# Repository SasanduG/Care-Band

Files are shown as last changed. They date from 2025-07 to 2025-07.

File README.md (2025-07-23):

# 🧠 Wearable Safety Device for Dementia Patients

An affordable, IoT-based **smartwatch system** designed to improve the safety and well-being of **dementia patients** by providing **real-time location tracking**, **fall detection**, and **caregiver alerts** via GSM. Developed by Team InnovaTech at the University of Moratuwa.
<p align="center">
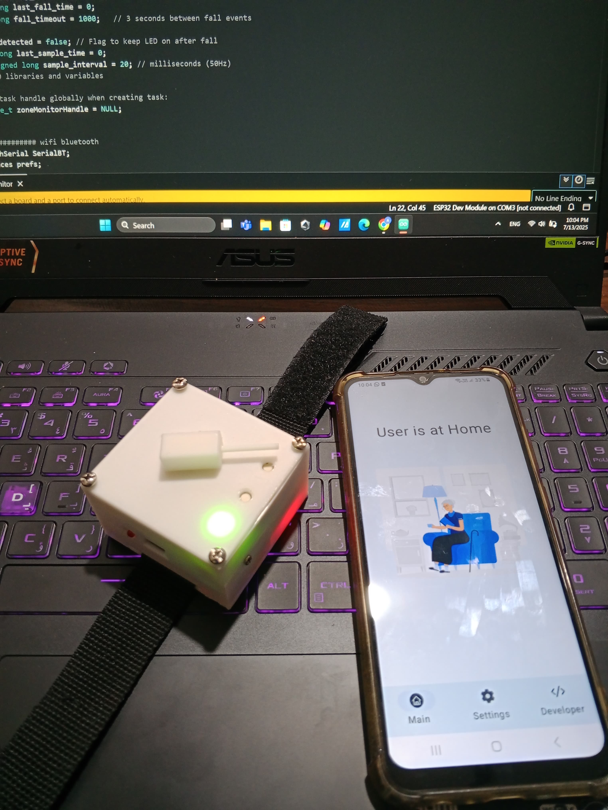
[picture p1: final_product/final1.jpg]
My Photo 1
  
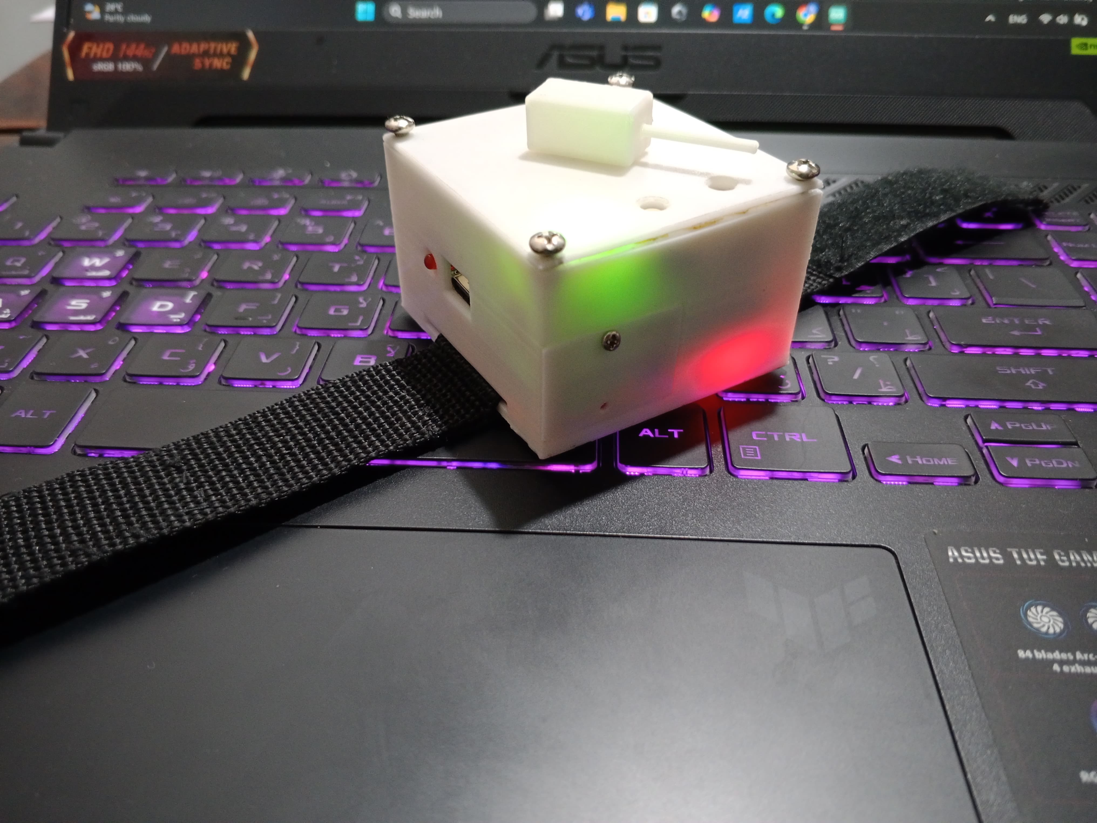
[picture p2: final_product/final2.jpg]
My Photo 2
  
</p>

---

## 📌 Overview

Dementia patients, especially in advanced stages, are prone to **wandering** and **accidental falls**, putting their safety at risk. This project proposes a cost-effective, comfortable, and practical **wearable solution** tailored for use in **Sri Lanka** and similar contexts. The device enables families and caregivers to monitor loved ones remotely using a mobile app and receive immediate alerts when a fall or unsafe movement is detected.

---

## 🎯 Key Features

- 📍 **GPS-Based Real-Time Tracking**
- ⚠️ **Fall Detection** using MPU6050 and ESP32
- 📡 **GSM Communication** via SIM800L (SMS & mobile data)
- 📲 **Android Mobile App** for caregivers with:
  - Live map tracking
  - Geo-fencing
  - Instant fall alerts
- 💡 **Status Indicators** for charging, connectivity, and alerts
- 🔋 **Rechargeable Battery** with safe charging module (TP4056)
- 🧰 **Custom Enclosure** and compact **PCB design**

---

## 🧩 Hardware Specifications

| Component | Description |
|---|---|
| **Microcontroller** | ESP32 WROOM-32 |
| **GPS Module** | NEO-6M |
| **GSM Module** | SIM800L |
| **Motion Sensor** | MPU6050 (3-axis Accelerometer + Gyroscope) |
| **Battery** | 3.7V 800mAh LiPo |
| **Charging Module** | TP4056 |
| **Enclosure** | 3D Printed (Custom Design) |

---

## 📱 Mobile Application (Android)

The custom-built mobile app (developed in **Kotlin**) provides:

- Real-time location display via **Google Maps API**
- Instant **fall and geofence** alerts
- Adjustable safe zone settings
- Simple and intuitive UI for caregivers

---

## 🛠 System Architecture

The system integrates:

- **ESP32** as the central controller
- **MPU6050** for fall detection
- **GPS** for live location updates
- **SIM800L** for GSM-based communication
- **Mobile app** for monitoring and control

All components are combined into a **compact PCB** and enclosed in a **watch-style casing** designed for elderly users.

---

## 🌍 Impact and Relevance

- Developed to meet the needs of families in **Sri Lanka**, where professional dementia care is limited.
- Uses **locally available** low-cost components.
- Final device cost is ~**8000 LKR**, aiming for **<10,000 LKR retail price** after optimization.
- Addresses growing elderly population and healthcare gaps.

---

## 👨‍🔬 Team Members

**Team InnovaTech – EN1190, University of Moratuwa**

- Wedamestrige A.N. (PCB & Circuit Design)
- Ranathunga R.J.K.O.H. (Mobile App Development)
- Garusinghe S.B. (Enclosure Design)
- Prabharsha H.W.D. (Enclosure Design)

---

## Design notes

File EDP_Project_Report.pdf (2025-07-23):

# Wearable Device for Dementia

# Patients

## EN 1190: Engineering Design Project


## University of Moratuwa

## Faculty of Engineering

Department of Electronics and Telecommunication Engineering

### Team InnovaTech

Name | Index

Ranathunga R.J.K.O.H. 230525U

Wedamestrige A.N. | 230687P
Prabharsha H.W.D. | 230495B
Garusinghe S.B. | 230197M

## Contents

1 Problem Description | 2
2 Product Feasibility | 4
3 Product Applications | 6
4 Product Specifications | 7
5 Product Architecture | 8
6 Enclosure | 11
7 PCB Design | 13
8 App Design | 15
9 Market Analysis | 17
10 Task Allocation | 18
11 Final Budget | 19

1

## 1 Problem Description

### Problem

Wandering is a common and worrying behavior among people living with dementia, especially in the moderate to advanced stages of the disease. Many patients leave their homes or care facilities without warning, often confused and unable to find their way back. This puts them at serious risk of accidents, injuries, getting lost, or even worse, if they are not found quickly.
In Sri Lanka, most families care for their loved ones at home, but with limited formal support services, providing round-the-clock supervision is a huge challenge. This constant responsibility causes significant stress and worry for caregivers. Sadly, traditional methods like manual watching or simple alarms often fail to prevent incidents. There is a real need for an affordable, practical, and easy-to-use solution that can help keep dementia patients safe and ease the daily burden on families who look after them.

### Justification for Problem Selection

Dementia is a significant and escalating global health crisis, profoundly impacting individuals and their families. This condition arises from damage to brain cells, disrupting their ability to communicate effectively. Such damage can stem from various causes, including diseases like Alzheimer’s, reduced cerebral blood flow (vascular dementia), atypical protein deposits (Lewy bodies), or other degenerative neurological conditions. Consequently, individuals with dementia frequently experience memory loss, disorientation, and a heightened propensity for wandering into unsafe environments, leading to potentially hazardous situations.
The global prevalence of dementia is staggering and on an upward trajectory. In 2020-2021, an estimated 55-57 million people were living with dementia worldwide, with approximately 10 million new diagnoses annually. Projections indicate a substantial increase in cases, reaching 82 million by 2030 and a remarkable 152 million by 2050. Dementia affects roughly 7% of individuals over 65, with prevalence rates escalating from about 3% in the 65-74 age group to nearly 50% in those 85 and older. The mortality rate associated with dementia has also seen a sharp rise, from 0.56 million deaths in 1990 to 1.62 million in 2019, with an anticipated 4.91 million deaths by 2050.
Sri Lanka mirrors this global demographic shift. By 2023, approximately 11.7% of its population was aged 65 or older, a notable increase from previous years, and this figure is projected to exceed 25% by 2041. In Sri Lanka’s rural and semi-urban areas, the prevalence of dementia among seniors is approximately 3.98%.
The worldwide aging of populations, including in Sri Lanka, directly correlates with an

2

escalating number of seniors and, consequently, a rise in dementia cases. This demographic trend underscores the urgent need to address the challenges posed by dementia.

### Proposed Solution

To address the growing challenges faced by dementia patients and their caregivers, we propose an affordable, wearable smartwatch system designed to improve safety and provide real-time monitoring. This solution combines modern IoT technology, low-cost hardware, and user-friendly design to help families manage dementia care more effectively, especially in Sri Lanka.
Our solution integrates a GPS module for real-time location tracking, a GSM module for communication with caregivers via mobile networks, and a motion sensor to detect abnormal movements such as falls. The smartwatch continuously monitors the patient’s location and sends alerts if they leave a predefined safe zone or if a fall is detected. This enables caregivers to respond quickly, improving patient safety and providing peace of mind. The device is designed to be lightweight, comfortable, and easy to use for elderly individuals, while also being cost-effective for families in Sri Lanka.

### Comparison with Existing Solutions

Although several tracking devices and smartwatches for dementia patients are already available globally, many of these products have significant limitations when applied in the context of Sri Lanka. Existing solutions tend to be:

- Expensive, making them inaccessible for many families in low- and middle-income

regions.

- Bulky or uncomfortable, reducing patient compliance for continuous wear.
- Limited local support and customization for the specific needs of Sri Lankan users,

such as language barriers or local network compatibility.

Our project aims to overcome these challenges by creating a cost-effective, easy-to-use smartwatch system tailored to local conditions. It uses affordable components, simple communication methods like SMS alerts, and a comfortable wearable design, making it suitable for everyday use by dementia patients and their caregivers in Sri Lanka.

3

## 2 Product Feasibility

### Technical Feasibility

The proposed solution is technically feasible because it uses widely available, cost-effective electronic components and well-established technologies. The ESP32 microcontroller, GPS, SIM800L, and MPU6050 are widely used and fully compatible with mobile app communication via internet or GSM.
- The ESP32 can connect to the internet via GSM or Wi-Fi to send patient location and

status data to a dedicated mobile app. This app provides caregivers with an intuitive interface for real-time monitoring, geo-fencing setup, and instant notifications.

- The mobile app can be developed using common frameworks such as Flutter or React

Native, which allow faster development and compatibility with Android devices.

- Instead of relying solely on SMS, the mobile app allows richer data (e.g., maps, reset

memory, restart, send message) and better user control while still using mobile networks for areas with limited Wi-Fi.

- The device is powered by a 3.7 V, 800 mAh, 25C LiPo battery, which provides a

lightweight, compact energy source suitable for continuous wearable use. The TP4056 module ensures safe recharging via USB.

- The MPU6050 sensor module combines a 3-axis accelerometer and a 3-axis gyroscope

to monitor the patient’s movements in real-time. It detects abnormal motion patterns such as sudden falls or impacts. The data is processed by the ESP32, and an alert is generated if an unusual event is detected.

The custom-designed PCB integrates all the essential modules on a compact board, ensuring stable electrical connections and efficient signal transmission while keeping the overall form factor small enough for a wearable enclosure. The smartwatch enclosure was designed using 3D modeling tools and fabricated through collaboration with Rysera Innovations and NMW Robotics, who provided high-quality 3D printing and prototyping services. This approach ensured that the enclosure met the required standards for fit, durability, and user comfort while keeping production local and cost-effective.

### Hardware Feasibility

The proposed smartwatch system is hardware-feasible because it uses affordable, widely available electronic components and proven fabrication methods that are within the capability of the team to assemble and test. Key aspects that prove hardware feasibility include:

4

- ESP32 microcontroller
- SIM800L GSM module
- MPU6050 accelerometer/gyroscope
- 3.7 V, 800 mAh, 25C LiPo battery
- TP4056 charging module
- GPS module

### Software Feasibility

The proposed system is also feasible from a software perspective because it relies on well-established development platforms, straightforward programming requirements, and technologies that are well supported by existing resources and tools.

- The ESP32 microcontroller will be programmed using the Arduino IDE which provide

extensive libraries and community support for modules like GPS, GSM (SIM800L), and MPU6050 sensors. This makes it easy to integrate location tracking, motion detection, and communication functions.

- The mobile app is being developed using Kotlin in Android Studio, which is the official

IDE for Android development. Using Kotlin ensures modern, clean, and efficient code that fully leverages Android’s capabilities. Native development provides better performance, easier access to phone features (like notifications, maps, and SMS handling), and smooth user experience for caregivers.

- Kotlin and Android Studio allow the team to build a clear, user-friendly interface

with map integration (e.g., Google Maps API), custom alerts, and easy controls for caregivers.

5

## 3 Product Applications

The proposed smartwatch-based tracking and safety system is primarily designed to assist dementia patients and their caregivers:

- Monitoring Dementia Patients
- Elderly Care
- Patient Monitoring in Hospitals

### Mobile application

The proposed system includes a custom-developed mobile application designed to work seamlessly with the smartwatch hardware. The mobile app acts as the user interface for caregivers, enabling them to monitor and manage the safety of dementia patients in real time. Our mobile application includes a lot of features like:

- Receives location and motion status data from the smartwatch via GSM/mobile net-

work.

- Displays the patient’s live location on an interactive map.
- Provides instant notifications if the patient leaves a predefined safe area (geo-fence) or

if a fall is detected.

- Allow caregivers to set or adjust safe zones easily.

6

## 4 Product Specifications

Parameter | Specification
Communication Method | GSM (SMS / Data for Mobile App Communica-
| tion)
Estimated Size | Compact, wrist-wearable form factor (custom
| PCB). 59mm x 55mm x 35.6mm enclosure box
Operating Time
Indicators | Charging LED: Shows charging status and
| charge completion
| Status LED: Indicates Wi-Fi connected, fall de-
| tected, or safe zone exited
Microcontroller | ESP32 Development Board
Location Module | GPS Module (NEO-6M)
Communication Module | SIM800L GSM Module
Motion Sensor | MPU6050 (3-axis Accelerometer + 3-axis Gyro-
| scope)
Battery | 3.7 V, 800 mAh, 25C LiPo Battery
Charging Circuit | TP4056 Li-Ion Charging Module

Table 1: Product Specifications

7

## 5 Product Architecture

The proposed smartwatch-based tracking and safety system is designed with a clear modular architecture that integrates hardware components, embedded software, and a native mobile application to deliver real-time monitoring and alert functionalities.
The hardware consists of several integrated modules mounted on a custom PCB:

### Hardware architecture

- ESP32 Microcontroller - Acts as the central processing unit, managing data from all

sensors and modules.

- GPS Module - Provides real-time location data to ESP32.
- SIM800L GSM Module - Handles mobile network communication, allowing the system

to send location and alert data to the mobile application via SMS or internet.

- MPU6050 Sensor - Continuously monitors the patient’s movements and detects falls

using accelerometer and gyroscope data.

- Power Supply - Powered by a 3.7 V, 800 mAh, 25C LiPo battery with a TP4056 charging

circuit.

- Indicators -

– Charging LED: Shows the battery’s charging status and charge completion.

– Status LED: Indicates Wi-Fi connectivity and provides visual alerts for fall detection or geo-fence breaches.

- Enclosure - All hardware is enclosed in a lightweight, ergonomic, 3D-printed smart-

watch casing for comfortable daily use.

### Software architecture

The system’s software architecture has two main parts:

1. Embedded Software:
- Runs on the ESP32 microcontroller.
- Continuously collects data from the GPS module and MPU6050 sensor.
- Detects safe zone breaches and falls using programmed logic.

8

- Communicate with the SIM800L module to send alerts and location data.
- Controls the status LED to provide immediate visual feedback.
2. Mobile Application:
- Developed natively in Kotlin using Android Studio.
- Receives data from the smartwatch via GSM/SMS or mobile data.
- Displays the patient’s live location on a map.
- Send notifications for safe zone exits and falls.
- Provides a simple interface for caregivers to view alerts and manage safe zone

settings.

### Block Diagram

Figure 1 shows the block diagram of our product.

1. ESP32
- The ESP32 is the central microcontroller. It collects data from the GPS, Ac-

celerometer, and (in your diagram) a Heart Rate Sensor. It processes this data to detect patient’s real-time location, patient’s motion status (e.g., fall detection), vital signs. It controls communication with the GSM module to send alerts.

2. GSM Module
- The GSM module connects the system to the mobile network. It sends SMS

messages or mobile data with the patient’s location and alert status (fall detected, left home, etc.). It may receive simple commands from the caregiver’s mobile app if needed.

3. GPS Module
- The GPS module receives signals from GPS satellites. It continuously provides

latitude and longitude data to the ESP32. This is used for real-time location tracking and geo-fencing.

4. Accelerometer
- The Accelerometer detects motion and orientation. It monitors sudden changes

in movement to detect falls. ESP32 uses this data to trigger alerts if abnormal motion is detected.

9

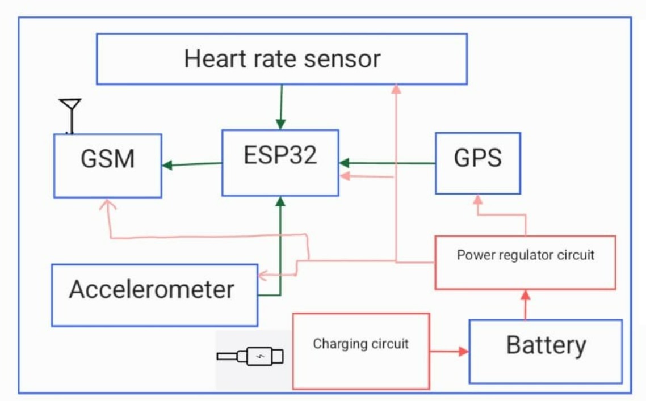
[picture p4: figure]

Figure 1: Block Diagram

5. Heart Rate Sensor
- This would monitor the patient’s pulse. The ESP32 can process this data for

additional health tracking.

6. Battery
- The Battery is a 3.7 V, 800 mAh LiPo cell. It provides portable power for the

entire system.

7. Charging Circuit
- This is the TP4056 charging module. It safely charges the battery via USB. It

also manages charging status (with the Charging LED).

8. Power Regulator Circuit
- Converts the battery’s raw 3.7 V to stable voltage levels required by the ESP32,

GPS, GSM, and sensors. Ensures each module gets the correct voltage and current to operate reliably.

10

## 6 Enclosure

### Initial Sketch

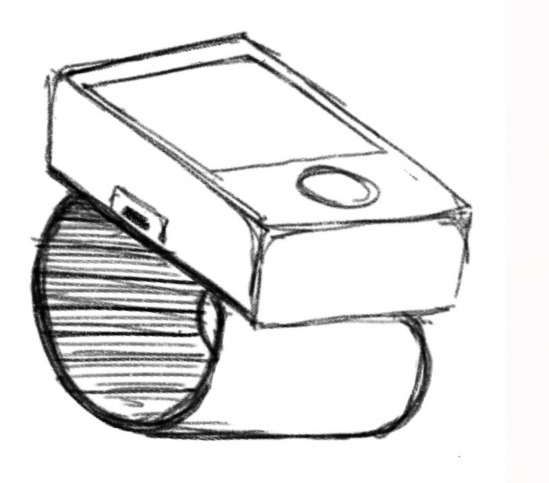
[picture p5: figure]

Figure 2: Initial sketch

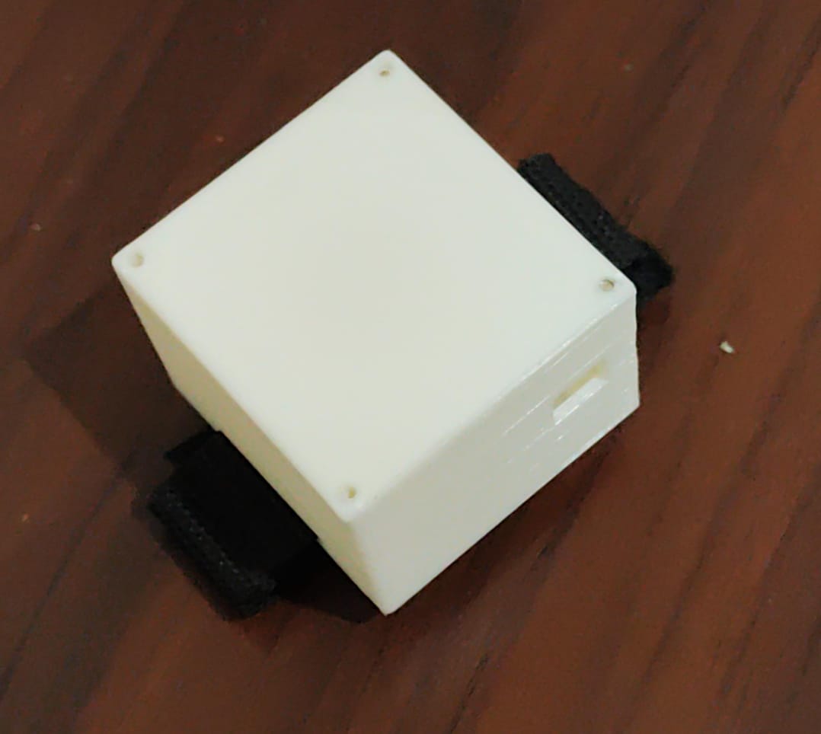
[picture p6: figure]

Figure 3: Final Product

11

### Final Enclosure

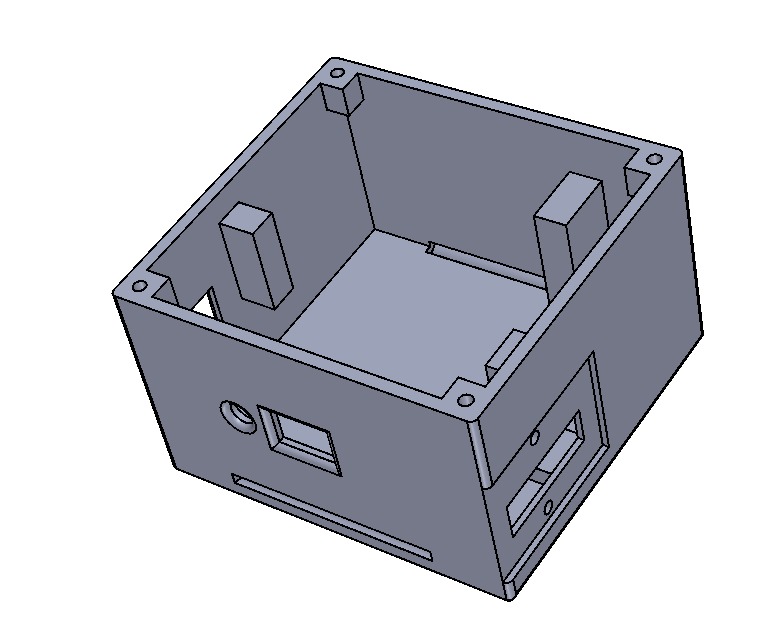
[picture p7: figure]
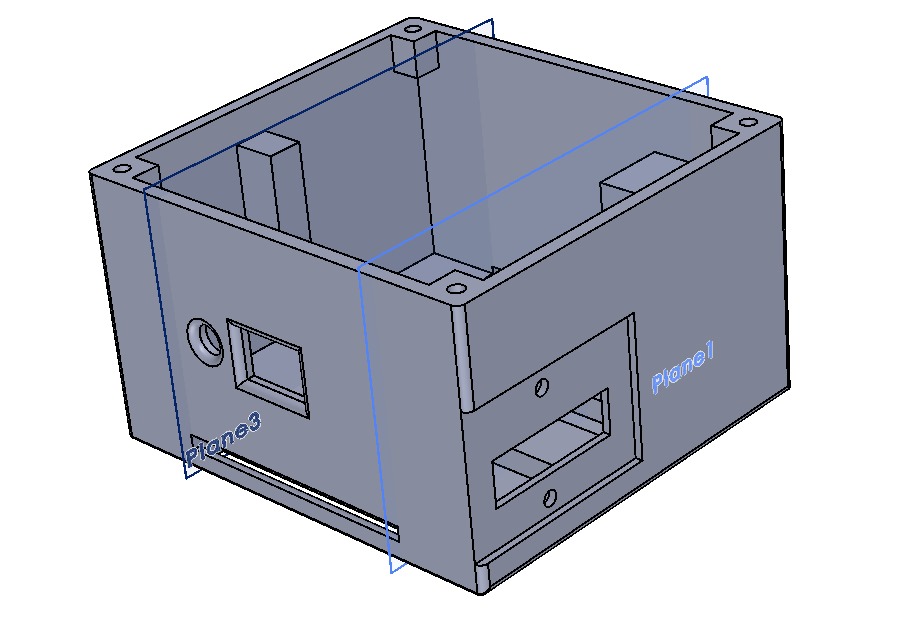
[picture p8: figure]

(a) Enclosure Design - View 1 | (b) Enclosure Design - View 2

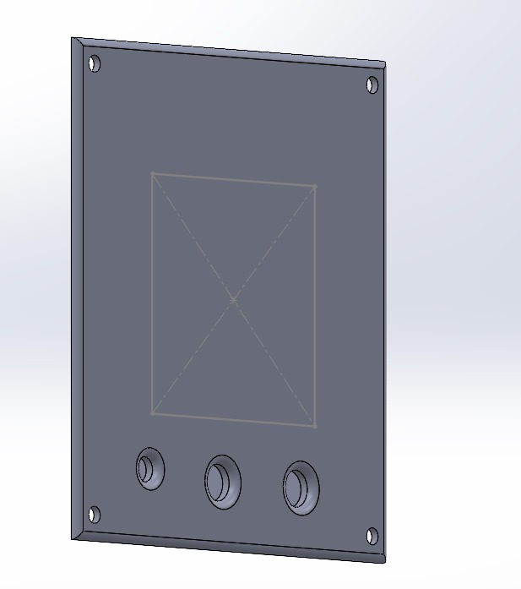
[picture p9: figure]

(c) SIM Lid | (d) Top Lid

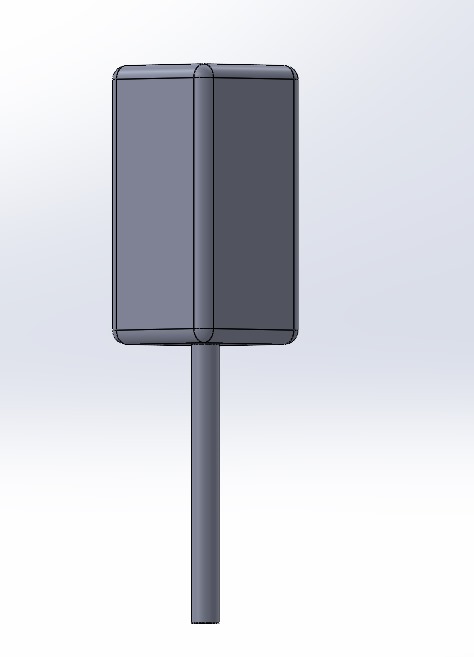
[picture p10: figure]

(e) Push Button
Mechanism
(f) Switch Part - View 1 | (g) Switch Part - View 2

Figure 4: 3D Model Components of the Smartwatch Enclosure and Assembly

12

## 7 PCB Design

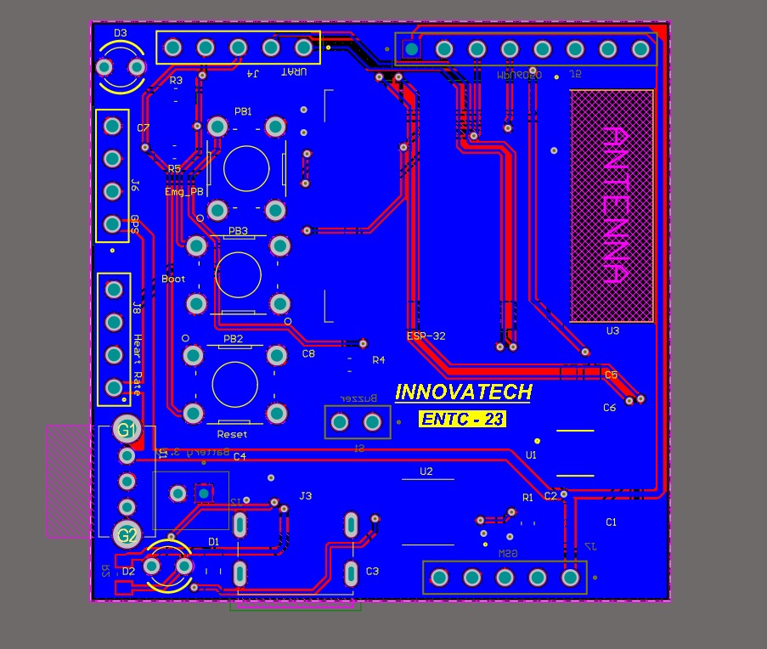
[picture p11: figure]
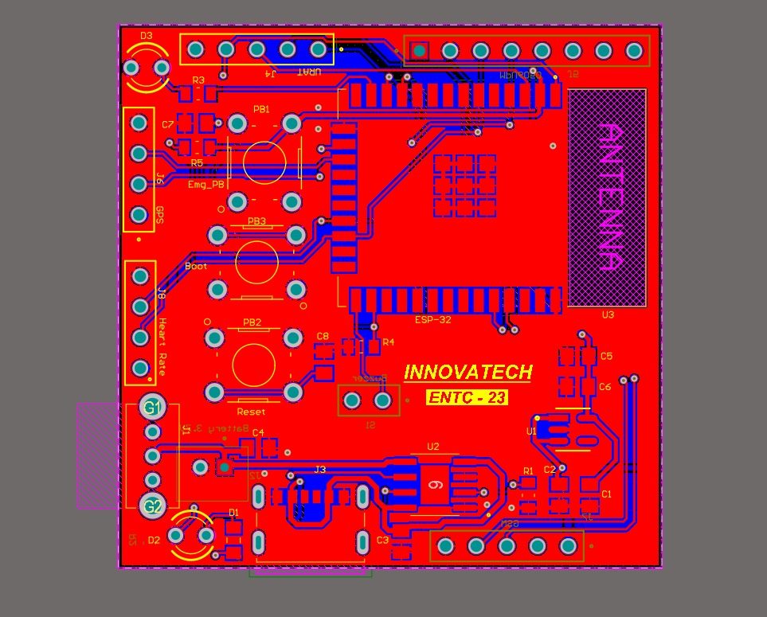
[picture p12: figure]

(a) Top layer | (b) Bottom layer

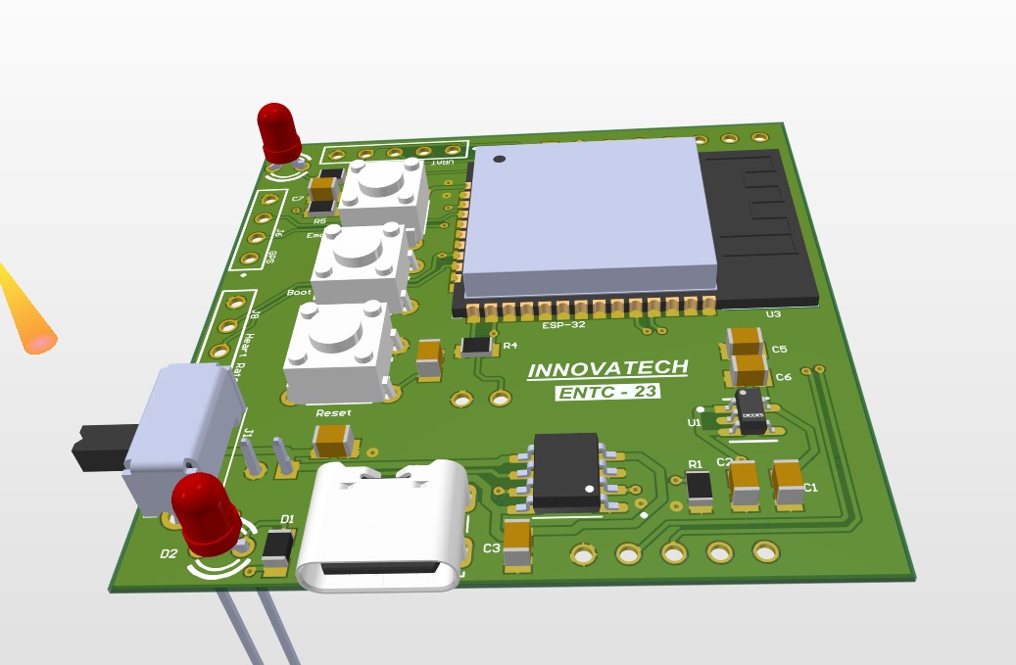
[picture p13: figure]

(c) 3D Model

Figure 5: PCB

13

### Schematic

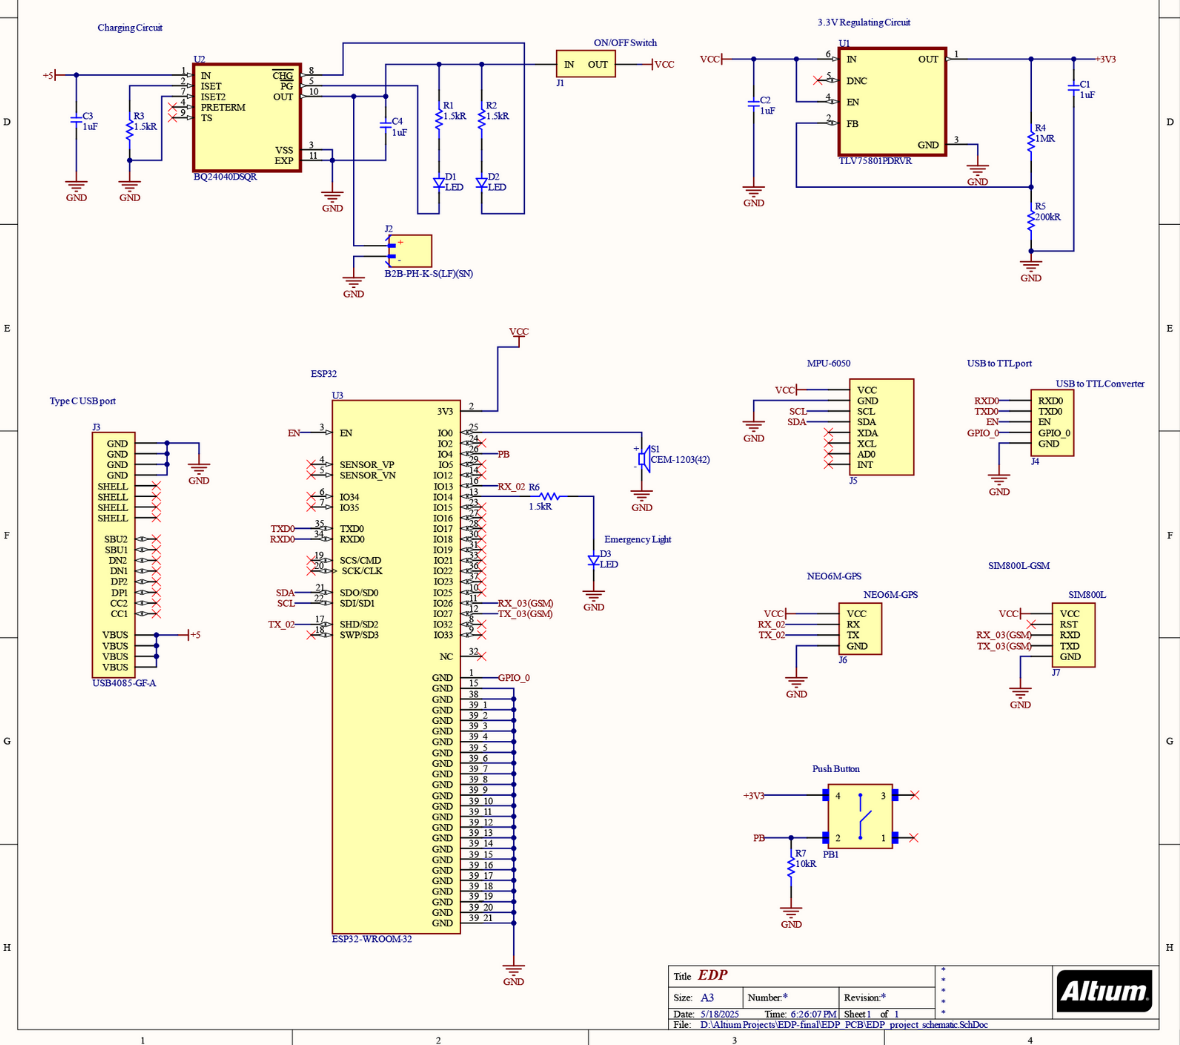
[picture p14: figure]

Figure 6: Schematic

14

## 8 App Design

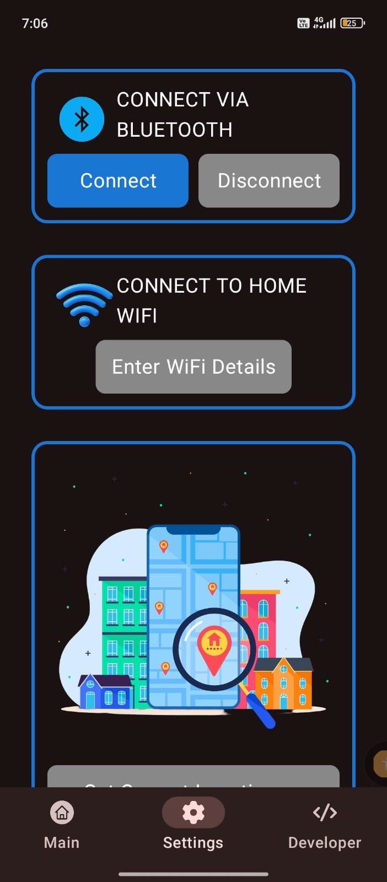
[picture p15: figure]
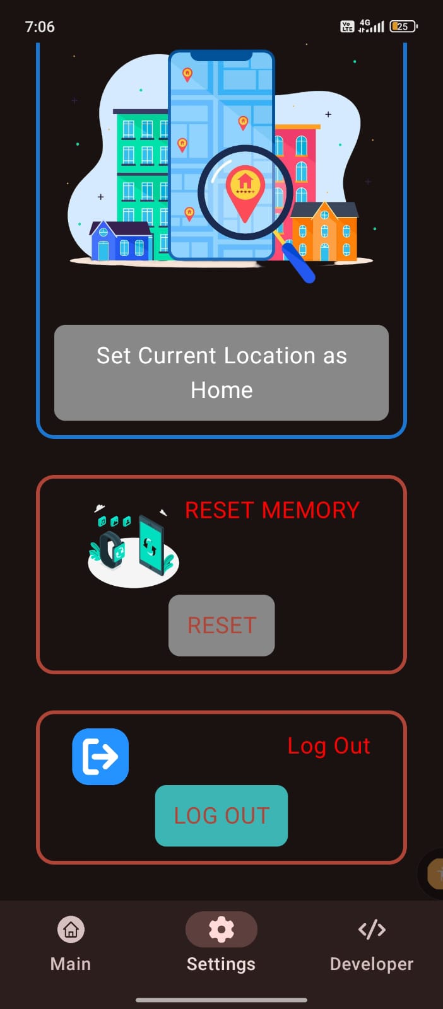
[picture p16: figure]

(a) Settings | (b) Device setup

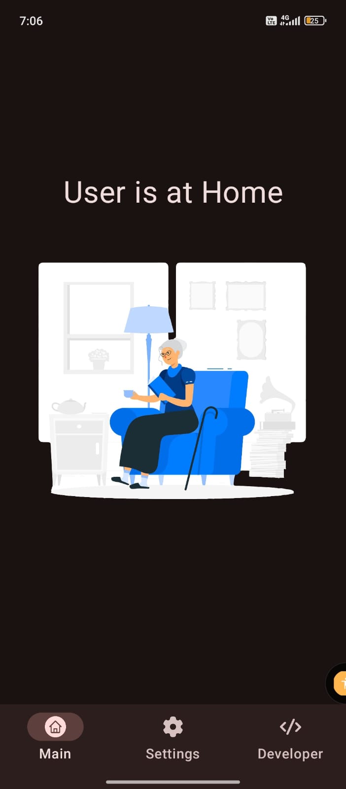
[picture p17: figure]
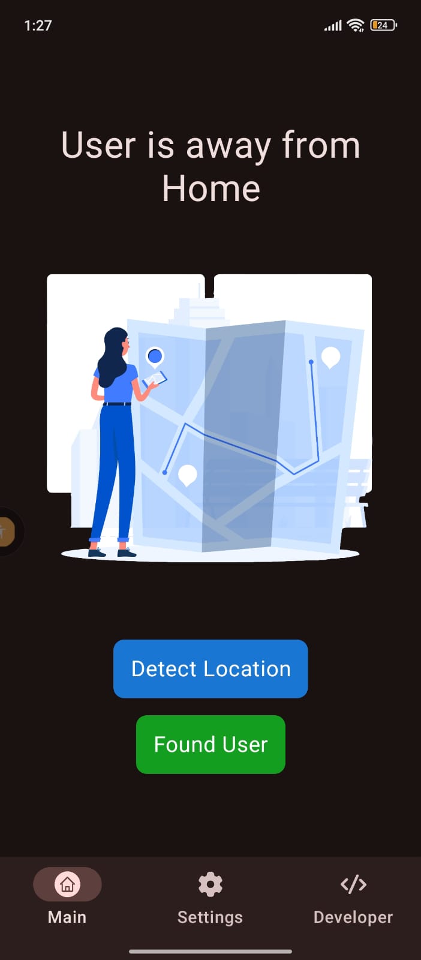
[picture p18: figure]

(c) User is at home | (d) User is away from home

Figure 7: App Design

15

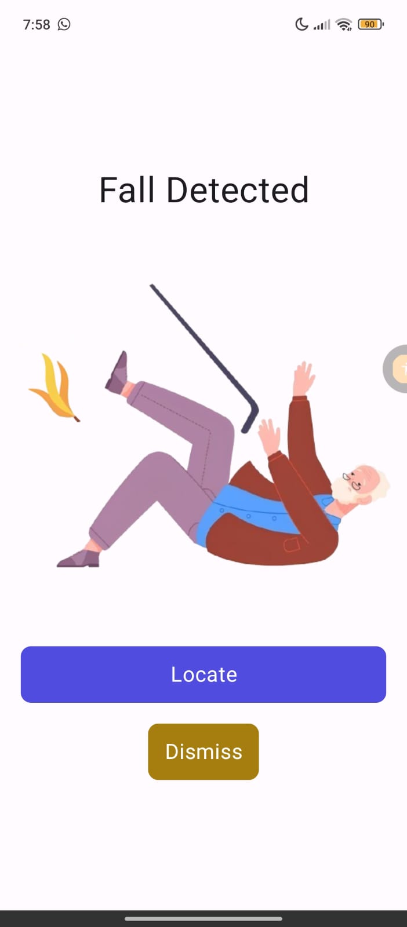
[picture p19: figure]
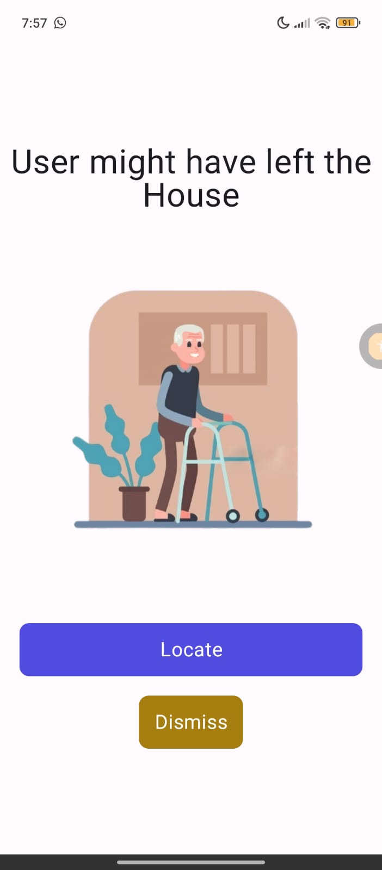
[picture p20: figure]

(a) Fall detected | (b) User have left the home

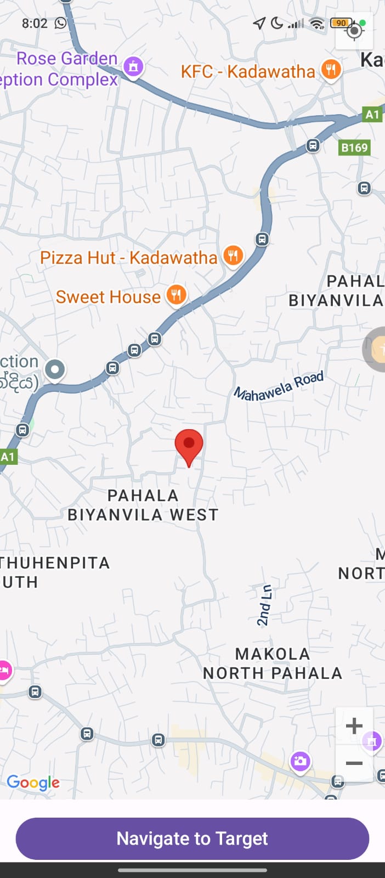
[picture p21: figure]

(c) Location Tracking

Figure 8: App Design
16

## 9 Market Analysis

The proposed smartwatch-based tracking and safety system addresses a growing need for effective patient monitoring solutions, especially for vulnerable groups such as dementia patients. The aging population, increasing cases of Alzheimer’s disease, and the lack of affordable, easy-to-use tracking devices create a significant market opportunity. Globally, more than 55 million people live with dementia, and this number is expected to double every 20 years due to aging populations (WHO, 2023). In Sri Lanka alone, an estimated 200,000–250,000 people live with dementia. A key challenge facing families is and accidental falls fromfalls from patients,nts, which can lead to severe injuries or death if not addressed quickly. Existing GPS-based patient tracking and medical alert devices typically range from LKR 8,000 to more than LKR 90,000, depending on features and brand. High-end solutions may also require monthly recurring subscription fees, which are unaffordable to many families in Sri Lanka. This highlights the clear need for a low-cost, locally produced alternative with integrated tracking, geofencing, and fall detection at an affordable price point. Sri Lanka is experiencing a steady increase in the elderly population, with people over 60 projected to make up more than 20% of the population by 2030. However, affordable technological solutions for elderly care are still limited in the local market. A locally developed, low-cost, customizable smartwatch system with tracking and safety features could fill this gap. Using low-cost modules, the product can be made more accessible than imported alternatives.

### Pricing

It cost about 8000 LKR for our product with available modules. But if we are mass producing it would cost less than this price. Including the costs of marketing, the salaries of the employees and other costs would add up. Keeping a considerable profit margin, price would be around 10,000 LKR.

17

## 10 Task Allocation

Name | Task allocation
Wedamestrige A.N. (230687P) | PCB Design, Circuit Analysis and De-sign
Ranathunga R.J.K.O.H. (230525U) | Mobile App Design
Garusinghe S.B. (230197M) | Enclosure Design
Prabharsha H.W.D. (230495B) | Enclosure Design

Table 2: Task Allocation

18

## 11 Final Budget

Component | Unit Price (Rs.) | Quantity | Total Price
ESP32 WROOM 32 Microcontroller | 1350 | 1 | 1350
SIM800L GSM Module | 1250 | 1 | 1250
NEO-6M GPS Module | 1100 | 1 | 1100
MPU6050 Sensor | 700 | 1 | 700
3.7 V, 800 mAh, 25C LiPo battery | 830 | 1 | 830
LED | 20 | 2 | 40
Push button | 5 | 2 | 10
PCB | 800 | 1 | 800
Enclosure | 900 | 1 | 900
Other Electronic components | - | - | 200
Total | | | 8180

Table 3: Final Budget

19

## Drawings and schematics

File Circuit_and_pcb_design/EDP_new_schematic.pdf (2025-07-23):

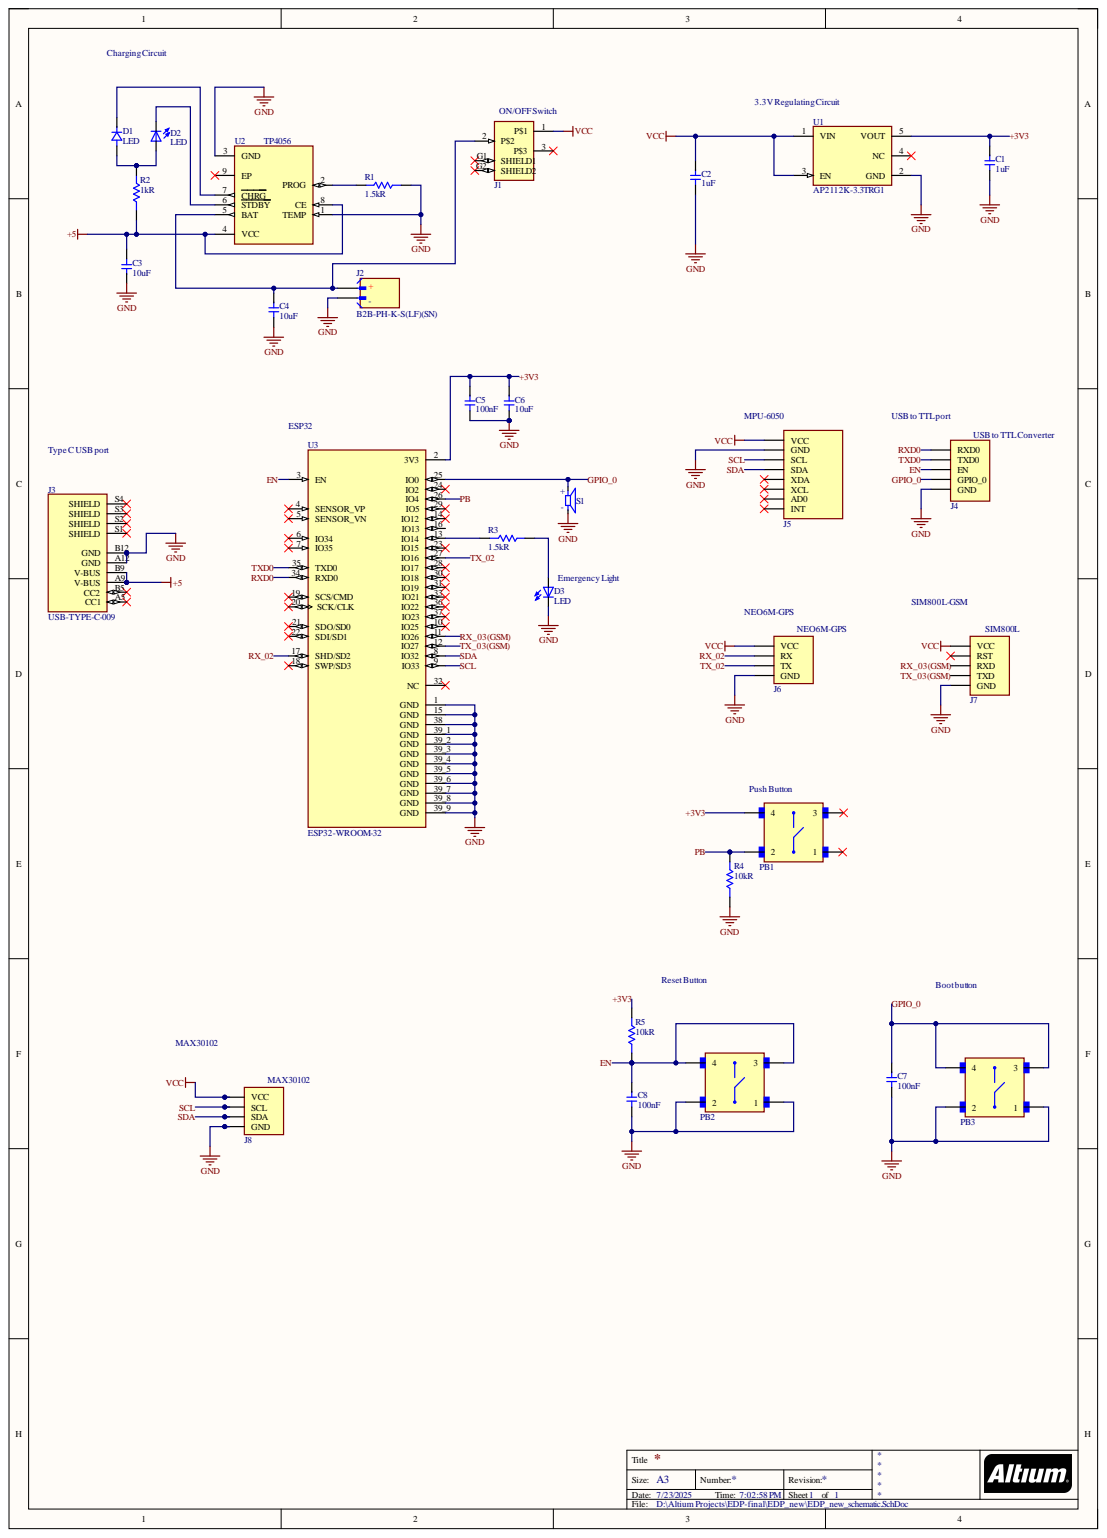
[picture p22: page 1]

VCC 4 | J2

* Title | * * * * *

Size: A3 | Number: * | Revision: *
Date: 7/23/2025 Time: 7:02:58 PM | | Sheet 1 of 1

D:\AltiumProjects\EDP-final\EDP_new\EDP_new_schematic.SchDoc

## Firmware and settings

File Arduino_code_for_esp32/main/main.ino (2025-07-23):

#include "BluetoothSerial.h"
#include <WiFi.h>
#include <ArduinoJson.h>  // Needed to parse JSON-formatted Bluetooth commands
#include <Preferences.h>
#include <HTTPClient.h>
#include <WiFiClientSecure.h>
#include <TinyGPS++.h>
#include <HardwareSerial.h>

// MPU6050 libraries and variables
#include <Wire.h>

const int MPU_ADDR = 0x68;  // MPU6050 I2C address
// const int LED_PIN = 15;     // GPIO pin connected to the LED
int16_t acc_x_raw, acc_y_raw, acc_z_raw;
// Calibrated values
float acc_x, acc_y, acc_z;
// Calibration offsets
float acc_x_offset = 0.0;
float acc_y_offset = 0.0;
float acc_z_offset = 0.0;
// Fall detection thresholds 0            iin
float impact_threshold = 1.5;        // g-force for impact
float low_activity_threshold = 1.3;  // g-force for post-impact stillness
unsigned long last_fall_time = 0;
unsigned long fall_timeout = 1000;   // 3 seconds between fall events

bool fall_detected = false; // Flag to keep LED on after fall
unsigned long last_sample_time = 0;
const unsigned long sample_interval = 20; // milliseconds (50Hz)
// MPU6050 libraries and variables

// Store task handle globally when creating task:
TaskHandle_t zoneMonitorHandle = NULL;


//############### wifi bluetooth
BluetoothSerial SerialBT;
Preferences prefs;

SemaphoreHandle_t wifiMutex;
volatile bool pauseMonitor = false;
volatile bool isUser_atHome = true;

// ###############  GPS
#define RXD2 17
#define TXD2 16
#define GPS_BAUD 9600
#define GPS_TIMEOUT 5000

TinyGPSPlus gps;
HardwareSerial gpsSerial(2);


struct GPSLocation {
  double latitude;
  double longitude;
};

// ENABLE BLUETOOTH
const int buttonPin = 0;  // Change if using another GPIO
bool btInitialized = false;

// GSM serial
HardwareSerial sim900(1); // Use UART1 (pins 26, 27)
#define GSM_RX 27  // Change according to your wiring
#define GSM_TX 26

int indicating_led = 14;

volatile bool wifiConnected = false;
volatile bool bluetoothEnabled = false;
volatile bool fallDetected = false;
volatile bool leftHome = false;

void LED_indicator(void *pvParameters) {
  pinMode(indicating_led, OUTPUT);

  while (true) {
    if (fallDetected) {
      // ⚠️ Fall detected - triple blink
      for (int i = 0; i < 3; i++) {
        digitalWrite(indicating_led, HIGH);
        vTaskDelay(200 / portTICK_PERIOD_MS);
        digitalWrite(indicating_led, LOW);
        vTaskDelay(200 / portTICK_PERIOD_MS);
      }
      vTaskDelay(1000 / portTICK_PERIOD_MS); // pause before repeating
    }
    else if (bluetoothEnabled) {
      // 📶 Bluetooth enabled - fast blink
      digitalWrite(indicating_led, HIGH);
      vTaskDelay(200 / portTICK_PERIOD_MS);
      digitalWrite(indicating_led, LOW);
      vTaskDelay(200 / portTICK_PERIOD_MS);
    }
    else if (wifiConnected) {
      // ✅ WiFi connected - solid ON
      digitalWrite(indicating_led, HIGH);
      vTaskDelay(500 / portTICK_PERIOD_MS);
    }
    else if (!wifiConnected) {
      // ❌ WiFi not connected - slow blink
      digitalWrite(indicating_led, HIGH);
      vTaskDelay(1000 / portTICK_PERIOD_MS);
      digitalWrite(indicating_led, LOW);
      vTaskDelay(1000 / portTICK_PERIOD_MS);
    }
    else if (leftHome) {
      // 🏠 Absolute left home - double blink
      for (int i = 0; i < 2; i++) {
        digitalWrite(indicating_led, HIGH);
        vTaskDelay(300 / portTICK_PERIOD_MS);
        digitalWrite(indicating_led, LOW);
        vTaskDelay(300 / portTICK_PERIOD_MS);
      }
      vTaskDelay(1000 / portTICK_PERIOD_MS); // pause before repeating
    }
    else {
      // Default: LED OFF
      digitalWrite(indicating_led, LOW);
      vTaskDelay(500 / portTICK_PERIOD_MS);
    }
  }
}



// ********************************* setup ************
void setup() {
  Serial.begin(115200);
  pinMode(indicating_led, OUTPUT);
  digitalWrite(indicating_led, LOW);

  pinMode(buttonPin, INPUT_PULLUP);  // Button connected to GND
  prefs.begin("wifi_prefs", false);
  wifiMutex = xSemaphoreCreateMutex();

  xTaskCreate(LED_indicator, "LED_indicator", 1024, NULL, 1, NULL);

  xTaskCreate(Zone_monitor, "ZoneMonitor", 4096, NULL, 1, &zoneMonitorHandle);
  gpsSerial.begin(GPS_BAUD, SERIAL_8N1, RXD2, TXD2);
  // SerialBT.begin("ESP32_BT_Device"); // Bluetooth device name
  // Serial.println("Bluetooth started!");
  WiFi.setAutoReconnect(false);

  Serial.println("Initializing SIM800L...");
  sim900.begin(57600, SERIAL_8N1, 27, 26);
  delay(2000);


  Wire.begin(32,33);
  Wire.setClock(400000);  // Fast I2C speed
  // pinMode(LED_PIN, OUTPUT);
  // digitalWrite(LED_PIN, LOW);  // LED off initially
  // Wake up MPU6050
  Wire.beginTransmission(MPU_ADDR);
  Wire.write(0x6B);
  Wire.write(0);  // Set sleep = 0
  Wire.endTransmission(true);
  // Calibrate offsets
  calibrateAccelerometer();
  Serial.println("Fall Detection Initialized.");

  xTaskCreate(detect_falls,"detect_falls", 6144, NULL, 1 , NULL);
  size_t freeStack = uxTaskGetStackHighWaterMark(NULL);  // NULL gets the stack usage of the current task
  Serial.print("freeStack: ");
  Serial.println(freeStack);
}

void Zone_monitor(void *pvParameters) {
  while (1) {
    if (pauseMonitor) {
      // If paused, skip this cycle (but not in the middle of one)
      vTaskDelay(100 / portTICK_PERIOD_MS);
      continue;
    }/*
     if (fall_detected) {
      if (xSemaphoreTake(wifiMutex, portMAX_DELAY)) {
          connectToSavedWiFi();
          send_message_Render("notify","fall_detected");
          Serial.println("Falling msg sent.");
          xSemaphoreGive(wifiMutex);
          fall_detected = false;

        }
      // If paused, skip this cycle (but not in the middle of one)
      vTaskDelay(5000 / portTICK_PERIOD_MS);
      continue;
    }
*/
    if (xSemaphoreTake(wifiMutex, portMAX_DELAY)) {

      
       // Re-check pause **after** taking mutex, in case Bluetooth handler set it in between
      if (pauseMonitor) {
        xSemaphoreGive(wifiMutex);
        vTaskDelay(100 / portTICK_PERIOD_MS);
        continue;
      }


      Serial.println("Zone monitoring...");
      if (isUser_atHome){
        monitorZone();
      } else {
        trackUser();
      }
      xSemaphoreGive(wifiMutex);
    }

    if (isUser_atHome){
      vTaskDelay(3000 / portTICK_PERIOD_MS);  // monitorZone() function delay
    } else {
      vTaskDelay(1000*20 / portTICK_PERIOD_MS);  // trackUser() function delay
    }
    Serial.println("done........");
  }
}


void loop() {
  // Check for button press to enable Bluetooth
  if (!btInitialized && digitalRead(buttonPin) == LOW) {
    // Serial.println("Button pressed! Shutting down all other activity...");

    // // Suspend Zone_monitor task only
    // if (zoneMonitorHandle != NULL) {
    //   vTaskSuspend(zoneMonitorHandle);
    // }

    // if (WiFi.isConnected()) {
    //   WiFi.disconnect(true);
    //   WiFi.mode(WIFI_OFF);
    // }

    // gpsSerial.end();
    // gsm.end();

    SerialBT.begin("ESP32_BT_Device");
    btInitialized = true;
    bluetoothEnabled = true;
    Serial.println("Bluetooth initialized");
  }

  // Only access SerialBT if it's initialized
  if (btInitialized && SerialBT.available()) {
    String incoming = SerialBT.readStringUntil('\n'); // Read till newline for safer JSON parsing
    Serial.println("Received: " + incoming);
    SerialBT.println("Echo: " + incoming);
    handle_bluetooth_command(incoming);
  }

  // You can add other non-Bluetooth logic here too
  delay(10);  // Short delay to avoid CPU hogging
}

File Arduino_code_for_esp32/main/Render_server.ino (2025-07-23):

/***********************HTTP Error codees******************
Response:{"error":"[Errno 5] Input/output error"} - It is works, msg has sent to the server
Error on HTTP request: -11   - Connections is fine, server might be turned off
Error on HTTP request: -1     - Connection Problem, check the code
*/
//********************************** Render server ***********

// APN for SIM card
const char* apn = "mobitel3g";  // e.g., "dialogbb" or "mobitel3g"

void send_message_Render(String command, String message) {
  // Make HTTPS or HTTP POST request
  if (WiFi.status() == WL_CONNECTED) {
    HTTPClient http;

    Serial.println("Sending over WiFi...");
    Serial.println("Message: " + message);
    Serial.print("IP Address: ");
    Serial.println(WiFi.localIP());
    Serial.printf("Free heap before HTTPS request: %u bytes\n", ESP.getFreeHeap());

    // Initialize HTTP (NO separate WiFiClient!)
    http.begin(serverURL);

    http.addHeader("Content-Type", "application/json");

    // Create JSON string
    String jsonPayload = 
      String("{\"x-api-key\":\"") + x_apiKey +
      "\", \"my-api-key\":\"" + my_apiKey +
      "\", \"command\":\"" + command +
      "\", \"message\":\"" + message + "\"}";

    // Send POST request
    int httpResponseCode = http.POST(jsonPayload);

    if (httpResponseCode > 0) {
      String payload = http.getString();
      Serial.println("Response:");
      Serial.println(payload);
    } else {
      Serial.print("Error on HTTP request: ");
      Serial.println(httpResponseCode);
    }

    http.end(); // Close connection

  } else {
    wifiConnected = false;  // for led status

    Serial.println("WiFi not connected. Using GSM...");
    //xSemaphoreGive(wifiMutex);

    useGSMToSend(command, message);
    

    
  }

  Serial.println("Sending process is end.");
}

// GSM***********************************************************
/*
void sendCommand(String cmd) {
  Serial.println("Sending: " + cmd);
  sim900.println(cmd);
  waitResponse();
}

void waitResponse() {
  long t = millis();
  while (millis() - t < 5000) {
    while (sim900.available()) {
      String s = sim900.readStringUntil('\n');
      Serial.println(s);
    }
  }
}*/

void sendCommand(String cmd) {
  Serial.println("Sending: " + cmd);
  sim900.println(cmd);
}


bool waitForResponse(const String& expected, uint32_t timeoutMs = 5000) {
  uint32_t start = millis();
  String buffer;
  while (millis() - start < timeoutMs) {
    while (sim900.available()) {
      char c = sim900.read();
      buffer += c;
      Serial.write(c);  // Echo everything
      if (buffer.indexOf(expected) != -1) {
        return true;  // Found it
      }
    }
    vTaskDelay(1);  // Yield to scheduler
  }
  return false;  // Timed out
}


// Main function
void useGSMToSend(String command, String message) {
  Serial.println("🔄 Starting GSM HTTP POST...");

  // Parse server IP and endpoint
  String url(serverURL);
  String serverIP;
  String endpoint = "/";

  if (url.startsWith("http://")) {
    url = url.substring(7);
  }

  int slashIndex = url.indexOf('/');
  if (slashIndex >= 0) {
    serverIP = url.substring(0, slashIndex);
    endpoint = url.substring(slashIndex);
  } else {
    serverIP = url;
  }

  Serial.println("🌐 Server IP: " + serverIP);
  Serial.println("🌐 Endpoint: " + endpoint);

  // Build JSON payload
  String jsonPayload = 
      String("{\"x-api-key\":\"") + x_apiKey +
      "\", \"my-api-key\":\"" + my_apiKey +
      "\", \"command\":\"" + command +
      "\", \"message\":\"" + message + "\"}";

  Serial.println("📦 JSON: " + jsonPayload);

  // 1️⃣ Start GPRS
  sendCommand("AT");
  waitForResponse("OK");

  sendCommand("AT+CPIN?");
  waitForResponse("READY");

  sendCommand("AT+CREG?");
  waitForResponse("+CREG: 0,1", 10000);

  sendCommand("AT+SAPBR=3,1,\"CONTYPE\",\"GPRS\"");
  waitForResponse("OK");

  sendCommand("AT+SAPBR=3,1,\"APN\",\"" + String(apn) + "\"");
  waitForResponse("OK");

  sendCommand("AT+SAPBR=1,1");
  waitForResponse("OK", 10000);

  sendCommand("AT+SAPBR=2,1");
  waitForResponse("+SAPBR: 1,1", 5000);

  // 2️⃣ Initialize HTTP
  sendCommand("AT+HTTPINIT");
  waitForResponse("OK");

  sendCommand("AT+HTTPPARA=\"CID\",1");
  waitForResponse("OK");

  sendCommand("AT+HTTPPARA=\"URL\",\"http://" + serverIP + endpoint + "\"");
  waitForResponse("OK");

  sendCommand("AT+HTTPPARA=\"CONTENT\",\"application/json\"");
  waitForResponse("OK");

  // 3️⃣ Prepare HTTP data
  String dataLenCmd = "AT+HTTPDATA=" + String(jsonPayload.length()) + ",10000";
  sendCommand(dataLenCmd);

  if (waitForResponse("DOWNLOAD", 5000)) {
    sim900.print(jsonPayload);
    Serial.println("📤 JSON sent, waiting for OK...");

    if (waitForResponse("OK", 10000)) {
      Serial.println("✅ Data accepted by modem.");
    } else {
      Serial.println("❌ No OK after data send.");
      return;
    }
  } else {
    Serial.println("❌ Did not get DOWNLOAD prompt.");
    return;
  }

  // 4️⃣ Start POST
  sendCommand("AT+HTTPACTION=1");
  if (waitForResponse("+HTTPACTION:", 10000)) {
    Serial.println("✅ HTTP POST action completed.");
  } else {
    Serial.println("❌ HTTPACTION response timeout.");
  }

  // 5️⃣ Read response
  sendCommand("AT+HTTPREAD");
  waitForResponse("OK", 5000);

  // 6️⃣ Clean up
  sendCommand("AT+HTTPTERM");
  waitForResponse("OK");

  sendCommand("AT+SAPBR=0,1");
  waitForResponse("OK");

  Serial.println("✅ HTTP POST completed.");
}
